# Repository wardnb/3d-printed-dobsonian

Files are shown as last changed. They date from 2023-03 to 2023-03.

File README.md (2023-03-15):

# 3d-printed-dobsonian
 I am starting this project because I needed to make some changes to a dobsonian telescope kit that I purchased and assembled at the beginning of 2022. I purchased the kit from Dennis Steele at [DobStuff](http://dobstuff.com/) and I believe he has since retired.

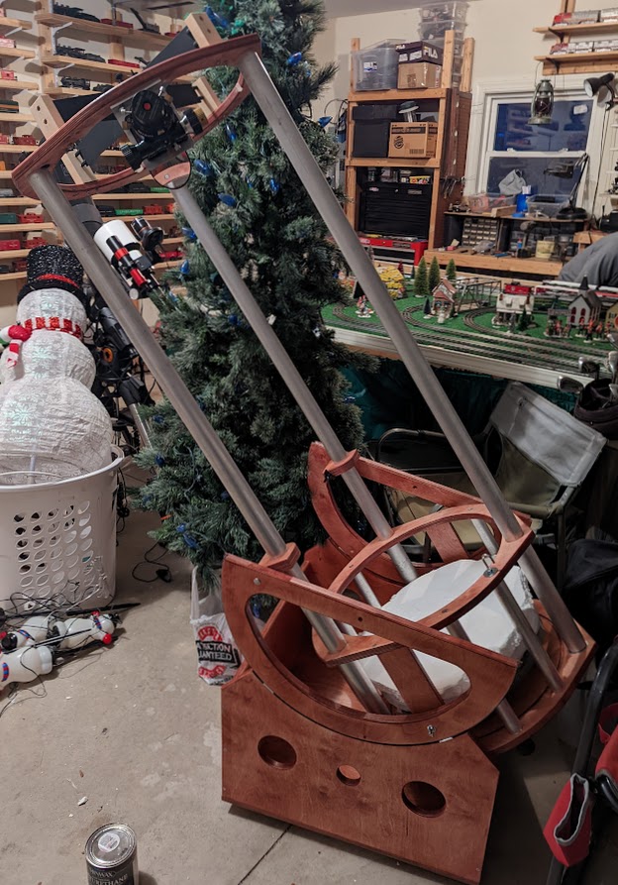
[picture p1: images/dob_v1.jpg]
Original Telescope


 I needed more adjustabiliy of the alignment of my focuser and the diagonal mirror, so the inital focus of this project is to build a cage for the secondary mirror and focuser. 

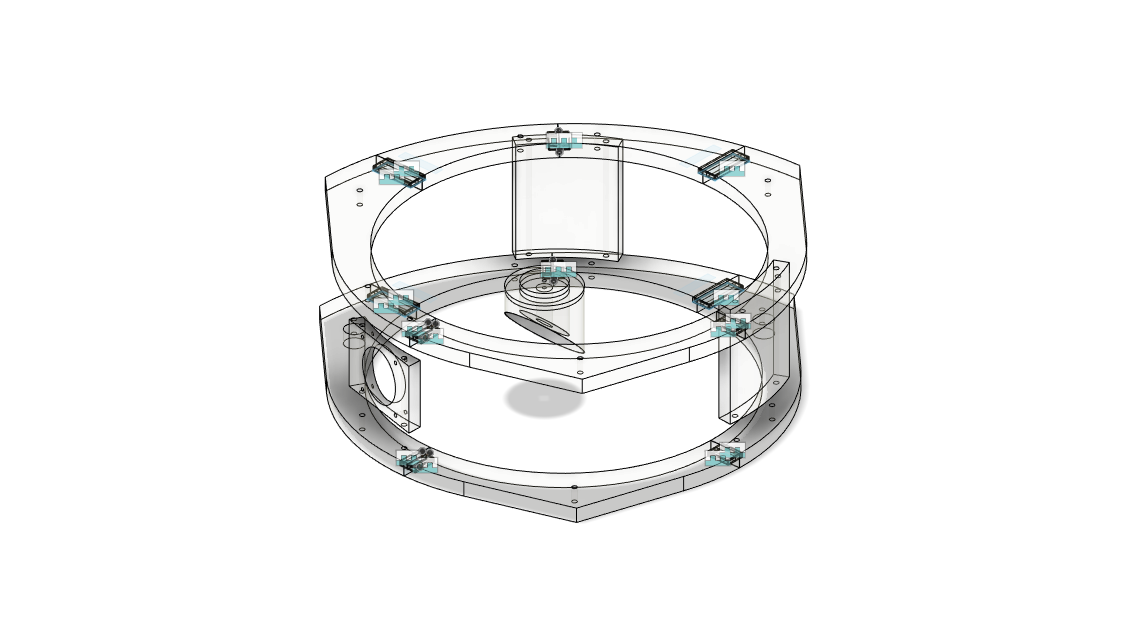
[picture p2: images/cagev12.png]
Upper Assembly


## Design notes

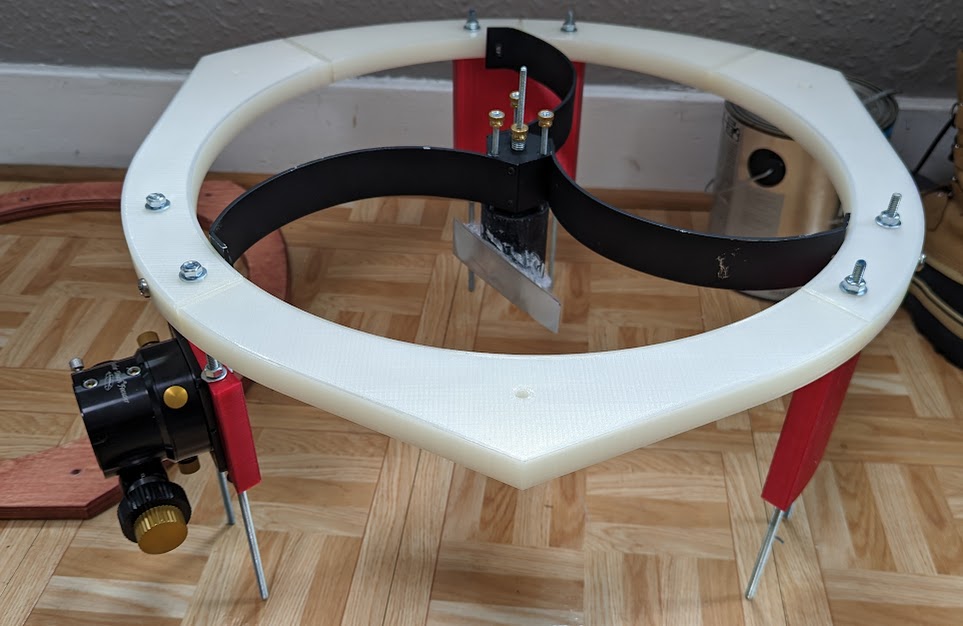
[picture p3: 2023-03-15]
images/in_progress.jpg

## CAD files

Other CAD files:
cagev11.f3d

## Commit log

2023-03-15 Added a picture of the telescope when I first built it. Added the fusion design for the cage.
    [cage v11.f3d]
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2026-10-18 Add parametric GoTo rebuild model (cage, spider, holder, truss, drives)
    CadQuery model and FE studies from the design review: 3/8in upper cage,
    quad spider on the posts, 3.5in self-aligning secondary holder, wide-pair
    truss on the mirror cage stub tubes, belt-on-rim SiTech drives. Includes
    STEP/DXF/GLB outputs and the viewer template.
    Claude-Session: https://claude.ai/code/session_01J7yJVsZjQn8SMrCb7MuBz2
2026-10-18 Update documentation for the GoTo rebuild
    Rewrite the top-level README around the two phases (retired printed cage,
    current GoTo rebuild), export the design doc to docs/design.md, add model
    renders, and link the model README to the exported doc.
    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
2026-10-18 Rewrite README, add CLAUDE.md, retire the 3D-printed cage
    README now describes only the GoTo rebuild. CLAUDE.md captures the
    session's decisions, rationale, model conventions, environment gotchas and
    open measurements for future sessions. Removes the printed cage design
    and photos (kept in git history) and syncs the latest model scripts.
    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
2026-10-19 Measure the scope, archive the DobStuff blog, choose carbon truss poles
    Crawl and archive the DobStuff blog (docs/dobstuff_kit_reference.md); log every
    as-built measurement taken 2026-10-18 in docs/measurements.md (bearings, rocker,
    ground board, azimuth bearing, mirror box, cell, struts, encoders).
    Model: replace the assumed mirror-cage geometry with measured values (18" ring,
    21.5" OD, 12.49" point, 11 3/8" inside height, top ring 7" above the mirror face,
    1 5/8" strut holes on a 10.68" radius, seven 1.25" spacers, 21 11/16" box width);
    export the cage height in the frame block for truss_fe.py. The measured box puts
    the top ring 7" below the altitude axis, so truss poles grow to 38.5"; de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
2026-10-19 Add truss joint detail model and viewer
    truss_joints.py builds the cone plugs, socket blocks on the stubs, and pair
    blocks under the cage ring from out/params.json, exporting GLB and STEP.
    site_joints/index.html is a phone-first three.js viewer with a cut-away and a
    section drawing, published as the Truss Joints artifact.
    Claude-Session: https://claude.ai/code/session_01PL9ehZ3XrESae6MWKWKhpd
2026-10-20 Struts and ring holes measured at 45 mm: update stubs, socket spigot, docs and joints viewer
    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
2026-10-20 Note the ring OD vs hole circle check and the outstanding measurements
    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
2026-10-20 Viewer: measured list, open list, carbon truss note; republished from the current model
    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
2026-10-20 Stub positions from the ring STEP: back holes r 10.625, point hole r 10.25, tip 12.125
    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
2026-10-20 Printed cage STEP corroborates the strut pilot positions; keep both STEPs in docs
    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
2026-10-20 Draw the true shield outline of the DobStuff ring; the back holes sit in the 12.56 in corners, no breakout
    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
2026-10-20 wooden_cage.step is the original upper ring: relabel, restore seven spacers, flag the box back outline as assumed
    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
2026-10-20 Decide to rebuild the rocker on the AltMill; queue the rocker and ground board drawings
    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
2026-10-20 Rocker and ground board drawn for the AltMill: rocker.py, export_rocker.py, DXFs, cut sheet, viewer v4
    - rocker.py: derive() sizes the rocker to the measured box (walls centred under the pads, 0.48 in off the
    box strips, 22.6 in inside), wall profile = arc 0.4 in under the 14 in rim with pad seats at +/-30 deg,
    horns at 42 deg, 4 in end boards under the box's swing circle; floor 24.05 x 27.42 in; ground board =
    hub + three arms + 30 in fixed ring (two halves) with az pads at r 12.75 and feet at r 14
    - bearings: rim + bar + 3 in web on the side strip, chord 3.62 in past the axis so the front pad stays
    under the arc down to 15 deg; 6.6 lb each (balance re-solved: mirror 13.5 in below t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
2026-10-23 Cut layout on AltMill-sized blanks: 24.4 x 48 strips, ring in three segments joined on the arms, shapely overlap check
    The cut sheet drew the parts on 60 x 60 sheets, but the AltMill bed is 48.6 x 24.4. Every blank is now a
    24.4 x 48 strip ripped from a 5 x 5 sheet and checked for margin and part gap. Ring halves (30 x 15) needed a
    blank each, so the ground ring becomes three 120-degree segments with the joints on the arms. The floor
    (24.05 x 27.42) is table-sawn and only drilled on the AltMill. Three 5 x 5 sheets in all.
    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
2026-10-30 Triangulate the upper cage: 1/4in slotted rings + six inverted-V diagonals
    Borrowed from the iOptron Photron 16in RC rear cage. cage_fe.py: 0.007 mm
    drift after 45 deg collimation vs 0.024 mm for the 3/8in post-only cage, and
    2 lb less metal. Inverted Vs land beside the truss pair blocks; the focuser
    bay stays open. Fit checks pass. Balance re-solved (mirror up 1.2in, axis and
    rocker walls down 1in); rocker DXFs and truss joints regenerated. Viewer v5,
    CLAUDE.md, README and docs/design.md updated.
    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
2026-10-30 cage_fe: Waypoint finder mount variants (ring riser, cradle between rings, post shoe)
    python cage_fe.py finder: ring riser tilts the finder 2.2 arcmin horizon->zenith
    (ring twist), cradle tied to both rings 0.47, post shoe 0.48; collimation unaffected.
    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
2026-10-30 Adjustable Waypoint finder cradle between the cage rings
    Replaces the riser bracket on the upper ring, which twisted the 1/4" ring
    (finder moved 2.2 arcmin horizon->zenith). The cradle bar ties both rings at
    150 deg via angle blocks; a tilt plate on a spherical-washer pivot with 10-32
    push-pull (pitch) and a yaw yoke aligns the finder to the eyepiece (+/-1 deg,
    ~3 arcmin per 1/8 turn). FE: 0.57 arcmin. DXFs + cut sheet for bar, plate,
    blocks, yoke. upper_cage_lb 12.7; balance and rocker re-solved (walls +0.35",
    all checks pass). Viewer, design doc and CLAUDE.md updated.
    Claude-Session: https://claude.ai/code/session_01J7yJVsZjQn8SMrCb7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
2026-10-30 Lighten the finder cradle (0.83 -> 0.50 lb) and fix the tilt plate's roll freedom
    Bar 1/4 x 1.0 (rings, not the bar, set the stiffness: 0.57' -> 0.70'), blocks
    and yoke from 1/2 plate, plate 0.85 wide. Plate now stands on three ball-point
    set screws (two-screw hinge at the mirror end) so it cannot roll about its
    centreline. Destiny towers no longer counted in cage metal (9.26 lb).
    upper_cage_lb 12.2; balance, rocker, viewer, doc and CLAUDE.md updated.
    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
2026-10-31 Mirror box FE: ply box + truss + mirror in one frame (mcage_fe.py)
    The box adds ~0.012 mm (0.028 rigid -> 0.040 as built); no doublers needed.
    Cell studs must sit next to the stubs (0.12 mm between them); pin stubs at
    both boards (0.022); keep spacer bolts tight. Sockets still dominate.
    Also fixes truss_fe zigzag apexes (30/150/270) so the bases use the measured
    stubs. Design doc, export and CLAUDE.md updated.
    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
2026-10-31 Mirror confirmed glued: glue-shear estimate, dial-indicator test, one-sided edge stops if > 0.1 mm
    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
2026-10-31 Cell photos: spring-stud cell has no sideways location; push-pull bolts in close-fit bushings
    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
2026-10-31 Mirror held by glue only (no clips or edge stops)
    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
2026-10-31 New 9-point flotation mirror cell (cell.py, export_cell.py, cell_support_fe.py)
    Debond the glued mirror; 6061 Y frame on three 5/16-24 bolts in bronze bushings
    clocked to the stubs, three flotation triangles on balls (pads at 0.431R and
    0.670R/+-33.1 deg, ~1 nm RMS from the plate FE), edge gussets at 225/315 spanning
    both sandwich plates (0.008 mm), guard posts with safety tabs, 80 mm fan.
    Cell 4.9 lb; balance, rocker, viewer, design doc and CLAUDE.md updated.
    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
2026-10-31 CLAUDE.md: material note (cast tooling plate for flat pocketed parts, steel inserts for loaded threads)
    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
2026-10-31 Cut plan: nested aluminium stock options (squares, circles, bought rings), 1/2in cell plate, bar/tube list, priced page
    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
2026-10-31 Cut plan: 21in circle options for 1/4 and 1/2 plate, editable quantities for quantity breaks
    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
2026-10-31 Cut plan: Midwest cast-plate prices pre-filled, 21in circles (tolerance -0/+0.125)
    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
2026-10-31 Truss joints: axial drawbolt + thumbwheel pocket (poles see 27 lb tension near the horizon), stub clamp collars, node 1.0in above stub
    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
2026-10-31 Viewer v6: truss drawn from truss_joints (sockets, drawbolts, thumbwheels, collars, pair blocks), sidebar overflow fixed, stale text updated
    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
2026-10-31 bearing_fe.py: D bearing + web joint FE (windup, gravity, fastener loads); side-panel option
    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
2026-10-31 D bearing joint: box-side back wing, 2 far dowels + 6 inserts (bearing_fe with the box side meshed); encoders position-only
    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
2026-10-31 Drive: no shifter, swappable 2:1/3:1 pulleys, cam-lever clutch on each arm
    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
2026-10-31 Drive modules: common swing arm (drive.py) on both axes, swappable 2:1/3:1 pulleys, spring + cam clutch, az pinion moved to y=6; fit checks and DXFs
    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
2026-10-31 Joint machining package: per-station printed wedge fixtures + G-code for cups and bores, 2.5D DXFs, sheet; pair blocks: 1.33in bond, stud off-centre, single dowel; wedge washers; ring holes match
    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
2026-10-31 Socket blocks: spigot becomes a separate turned part (bolted + bonded) so the socket stack is 3.6in, not 5.1in, on the AltMill; G-code rapids at block top + 0.5 (fixed Z1.0 was below the block top); 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
2026-11-04 Joint machining: print-ready wedge fixture STLs (8, rebased to z=0) + zip
    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
2026-11-04 [local] Wedge fixtures sliced and queued on trident1; headless slicing tool; first requests to the cloud session
    - local/slice_trident.py: OrcaSlicer CLI with the trident1 presets flattened (inherits resolved), optional Moonraker upload
    - docs/requests.md: fixture print status; ask for a block-corner WCS (PLA shrink ~0.3 mm over the fixture); how is the fixture held down
    Claude-Session: https://claude.ai/code/session_017fcDuu32go6zbmZAab1Ngd
2026-11-04 [local] Fixtures resliced in ASA (no PLA for clamped fixtures); brim; ASA is the slicer default
    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
2026-11-04 Joint machining: print README for the wedge fixtures (slicer settings, post-print checks, AltMill setup)
    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
2026-11-04 Joint machining: Z touch-off on the block top, fence-corner caliper check, 3 hold-down holes per fixture (answers docs/requests.md)
    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
2026-11-04 [local] Fixtures resliced from the v2 STLs (hold-down holes): ASA, 30% cubic, shrink 99.5%; slicer gets --fset
    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
2026-11-07 Roller bearings on both axes replace the PTFE/Ebony Star pads
    roller_study.py: loads, Hertz/foundation stress, friction (~11 in-lb alt,
    ~7 az vs 145/183), gearbox margin 8.8x/20x, preload check, brake force.
    rocker.py bearing_kind="rollers": R10 rollers in 6061 blocks on wall
    notches at +/-30 deg with lateral tabs, 1/16x5/8 track strips on the rims,
    four az rollers hung through floor cutouts on a 1/8 track ring, FR6 pivot.
    export_rocker: track/plate DXFs nested on 12x48, block STEPs, checks.
    drive.py pinion hub <= 12.5 mm. Cut plan BUY/BARS, viewer, CLAUDE.md
    Decisions (bearings, drives, backlash, rocker), design doc section.
    Claude-S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
2026-11-07 Predictions register: every simulated number with its assumptions, test method and a Measured column
    docs/predictions.md (collimation drift, finder, D joint windup, rollers/friction/drives,
    mirror support, optics, pointing, weights; fresh cage_fe/truss_fe/mcage_fe/cell runs),
    pointer in CLAUDE.md, summary in the design doc.
    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
2026-11-08 Truss joints: gib clamp replaces the unreachable drawbolt thumbwheel
    Cap screw head-down in the plug nose through a 0.70 apex hole; 5/8 gib pin in a
    horizontal bore from the socket block's outside face, 8 deg wedge under a spherical
    washer, driven by a 1.25" knob through a steel retainer plate (~200-300 lb from 5 in-lb).
    joint_machining: apex hole in the cup op, Op2 gib bores + tap drills (no fixture) with
    G-code, retainer plate DXF; pocket and wedge washer removed. Viewers, cut plan, docs.
    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
2026-11-08 Drawing sheets (drawings.py) + az roller block fix found by drawing it
    Hidden-line dimensioned sheets from the solids: socket block, gib + plate, cone plug,
    roller blocks -> out/drawings/all_sheets.pdf. The az roller block (1.1 tall) was cut in
    two by the 1.19 roller slot and its roller faced up: now 1.5 tall, roller side down,
    0.79 below the floor on 4x #10-32; floor +0.4 (rocker 16.0, eyepiece 64.2).
    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
2026-11-08 Motor mount: four #6-32 clearance holes on a 1.63 in square (measured); plate B slots, lobe r 1.32
    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
2026-11-08 Motor flange: no pilot boss, countersunk holes -> shaft clearance slot + #6-32 flat heads
    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
2026-11-09 Encoders: tape reader identified as RLS RLC2HD (fixed-code resolution); D20 variant noted as the cheap alt option if ever wanted
    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
2026-11-09 [local] requests.md: pair_30_L fixture printed 2026-11-08; adhesion recipe (bed 110, Z -0.06, washed plate) and the AFC/Bowden saga
    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
2026-11-09 [local] requests.md: pair_30_R fixture printed 2026-11-09 (6 h 17 min, Z -0.07); six fixtures remain
    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
2026-11-10 BUY: full cutting-tool, workholding and consumables list for the whole build (replaces the sparse shop-consumables group); cut plan republished
    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
2026-11-10 [local] requests.md: internal-bridge-flow reslice of the five queued fixtures
    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
2026-11-10 [local] requests.md: pair_150_L fixture printed 2026-11-10 (6 h 38 min)
    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
2026-11-10 [local] slice_trident.py --pa: pressure advance on the PRINT_START line (fixtures ran the stale global 0.037); pair_150_R started
    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
2026-11-10 [local] requests.md: pair_150_R fixture printed 2026-11-10; all four pair fixtures done, sockets wait on ASA
    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
2026-11-12 [local] requests.md: layer-shift diagnosis (stepper_x lost steps between 16:53 and 17:23)
    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
